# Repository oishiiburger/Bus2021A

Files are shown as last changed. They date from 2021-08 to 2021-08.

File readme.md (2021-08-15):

# Bus 2021A

This is a quick n' dirty bus design for a hobbyist computer system based around the [WD65C02](https://en.wikipedia.org/wiki/WDC_65C02). It is not meant to be fancy, but it should be functional. Features of the 65C02 which are unique to the WDC version are not exposed to the bus (i.e. VPB Vector-Pull Output, MLB Memory-Lock Output, and BE Bus Enable input). 4 pins (USER1 through USER4) are provided for peripheral expansion / experimentation / whatever.

The purpose of the bus is to allow for the use of a custom backplane so that several small boards to be easily connected. The backplane design is below, and protoboards intended for this bus are to come.

The bus mapping is [here](./Bus2021A.txt), but also printed on the backplane board.

## Bus 2021A backplane - 5 slot

The backplane features spots for 5 female pin headers, a DJ jack for 5v power and a power jumper (which can be broken out to a switch), a power LED, and a reset switch which is tied into the bus. 

A future revision might include blinkenlights on the backplane, but for now there will be space for those to be easily placed on one of the protoboards.

| PCB | Schematic |
| --- | --- |
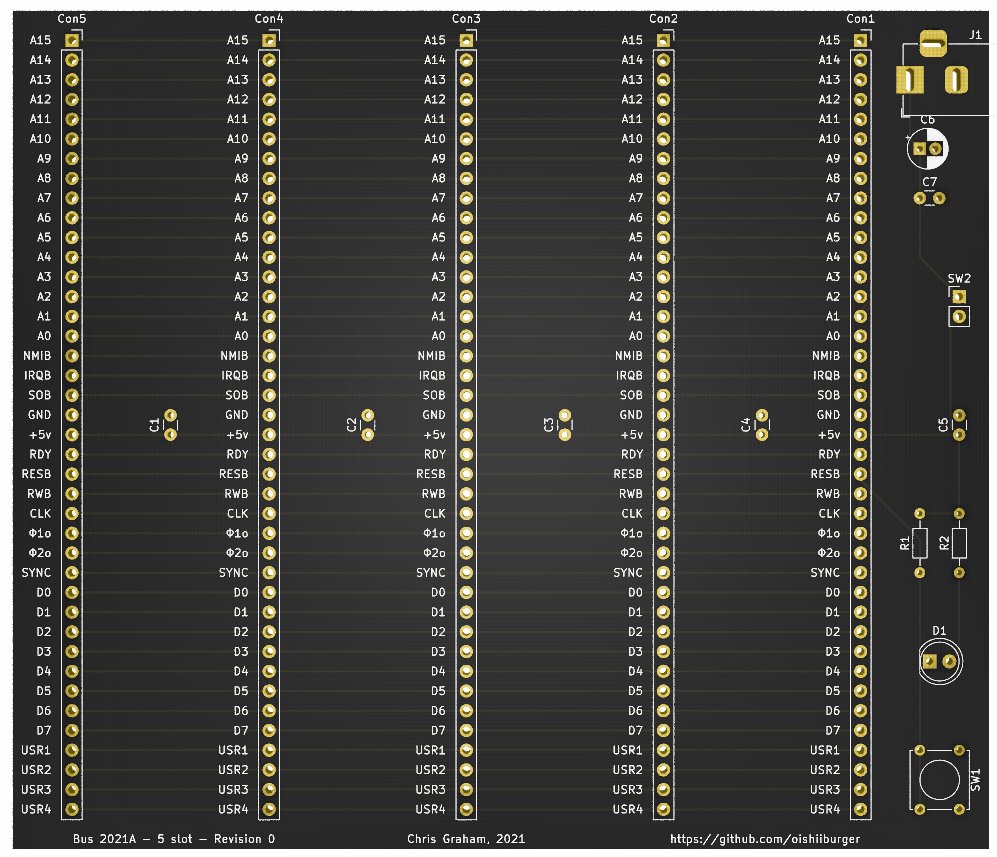
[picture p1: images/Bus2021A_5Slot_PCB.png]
Bus 2021A Rev0 PCB
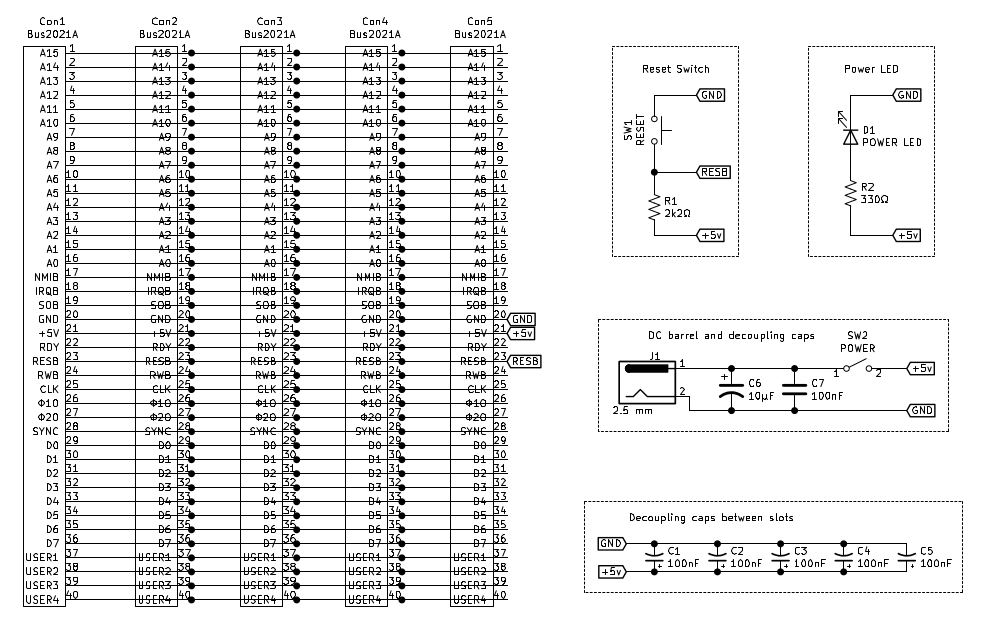
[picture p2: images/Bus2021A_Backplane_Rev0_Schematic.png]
Bus 2021A backplane - 5 slot schematic
|  |  |

Necessary kicad files are in [Bus2021A_5Slot](./Bus2021A_5Slot).

## Bus 2021A Protoboard

The protoboard is intended to connect with the backplane using a 90-degree pin header. It is designed as an easy and straightforward platform to interface with the bus and features a total project grid of 30x40 (1200 solder points). It has power rails vertically on either side with ground also horizontal on row 6, and the bus overall extends into the first three rows from the bottom (effectively a stripboard), all to keep distances shorter for wiring. The project grid not counting the rails or bus extension is 912 solder points. The board is labeled front and back on both axes.

The overall layout is:

```
Rows 1-3    :   Bus extension
Rows 4-5    :   Connected vertically
Rows 7-30   :   Project space (between power rails)
```

The purpose of the vertical connection between rows 4 and 5 is for easy installation of blinkenlights on the board using individual LEDs and resistors or LED bar graphs and resistor arrays. These rows can also be used for arbitrary circut connections without having to solder and resolder multiple wires.

Necessary files are [here](./Bus2021A_Protoboard).

| Protoboard front | Protoboard rear |
| --- | --- |
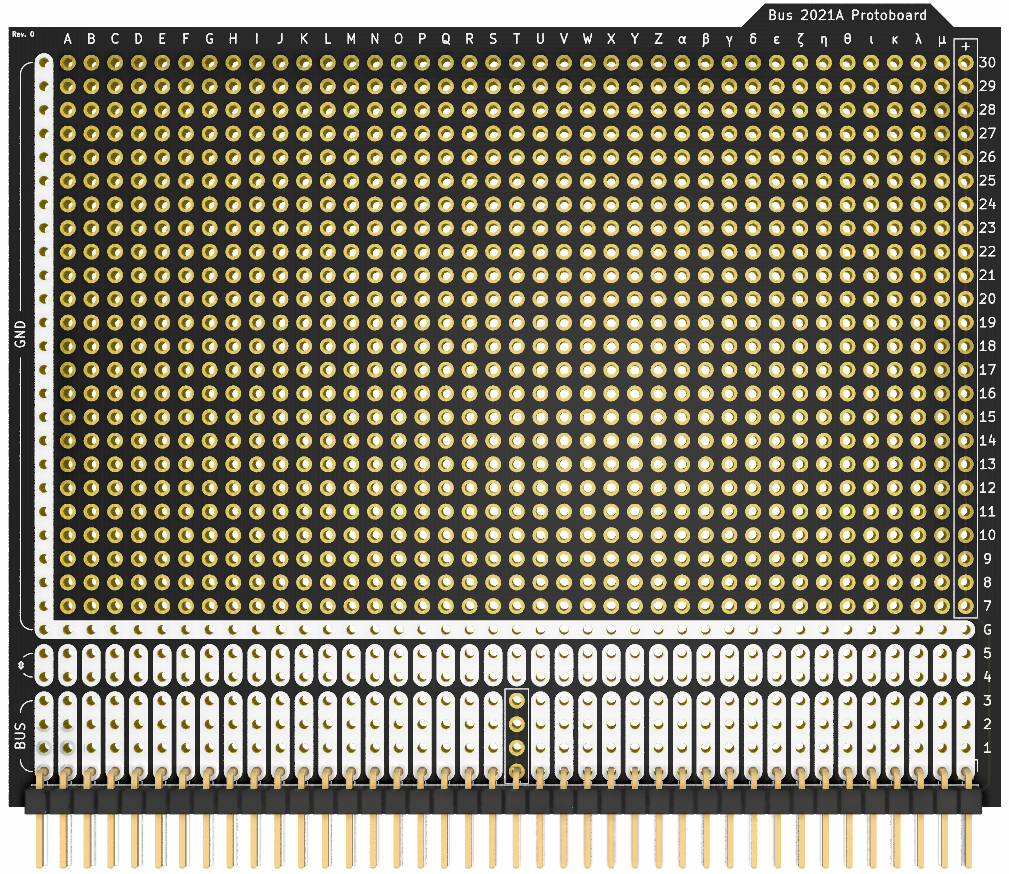
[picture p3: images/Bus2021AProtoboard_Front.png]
Protoboard front
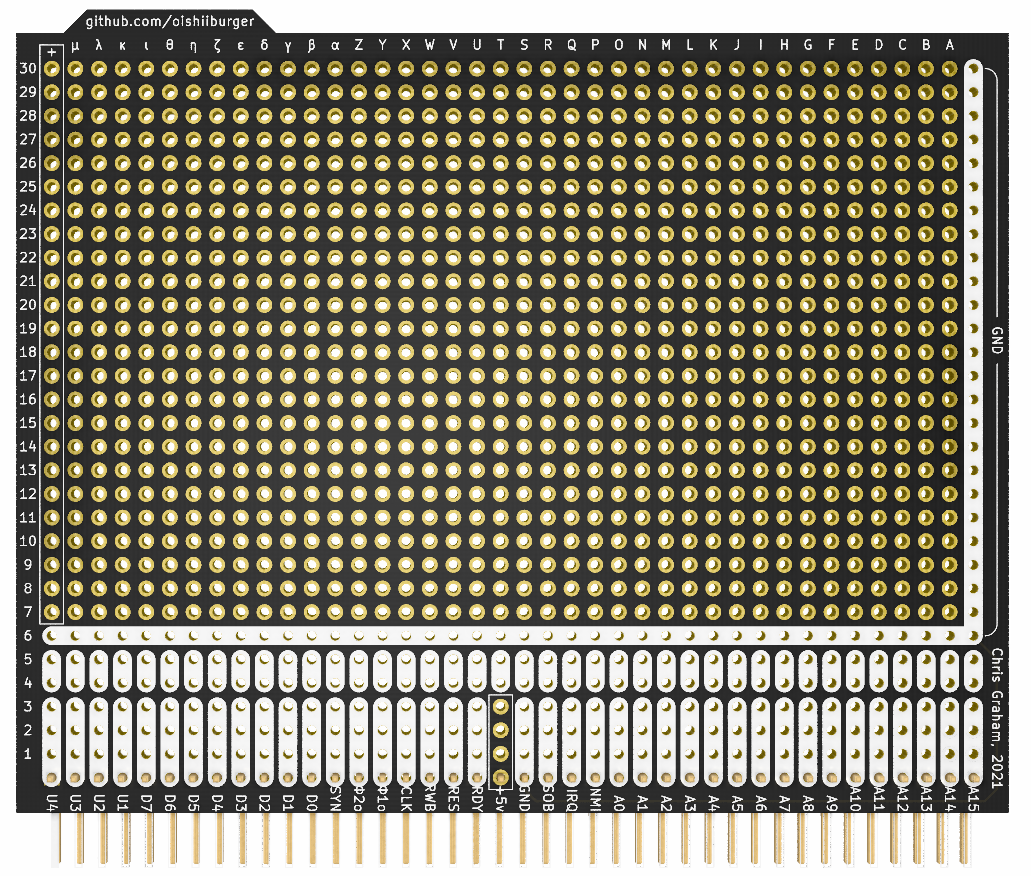
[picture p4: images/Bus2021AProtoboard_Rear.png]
Protoboard rear
|  |  |

## Symbols / footprints

A symbol for the bus and a footprint for the headers on the protoboard are in the [library folder](./Bus2021A_library).

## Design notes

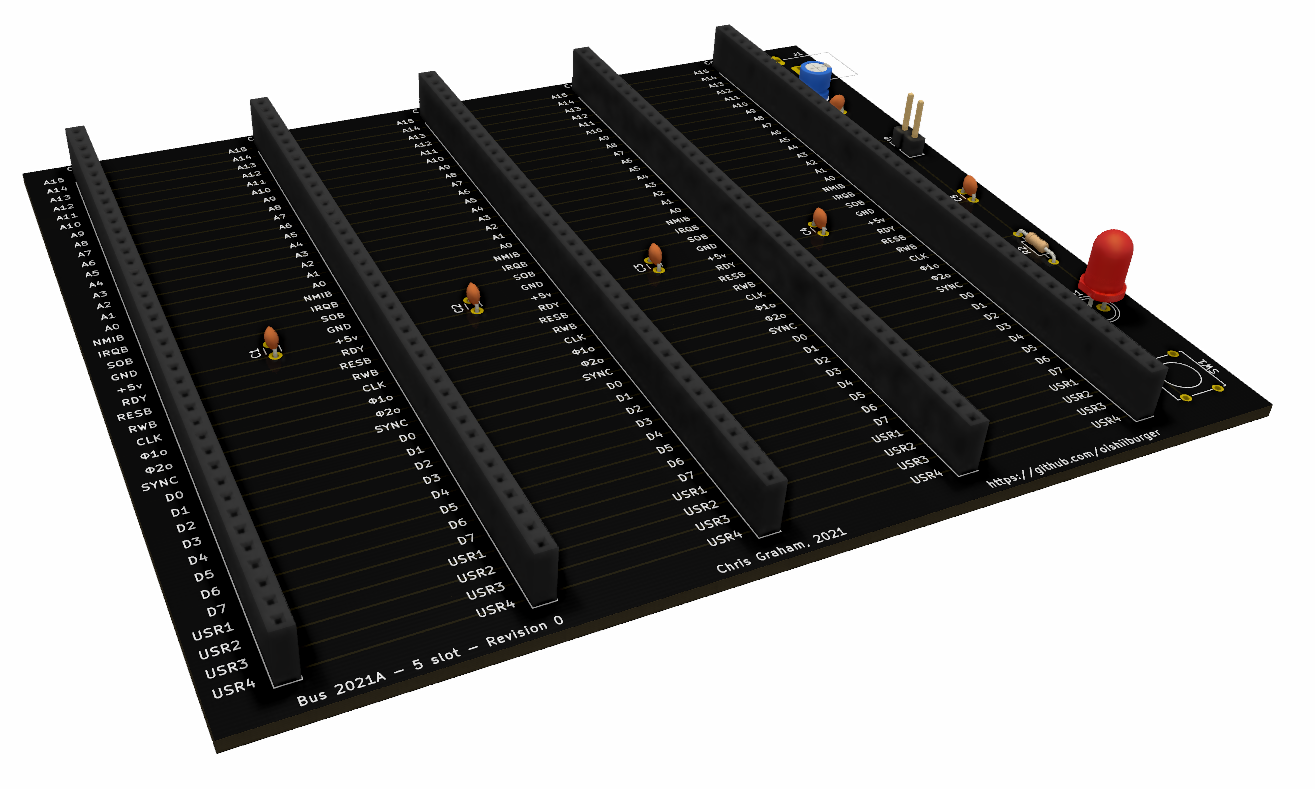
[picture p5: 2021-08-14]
images/Bus2021ABackplane_Side.png

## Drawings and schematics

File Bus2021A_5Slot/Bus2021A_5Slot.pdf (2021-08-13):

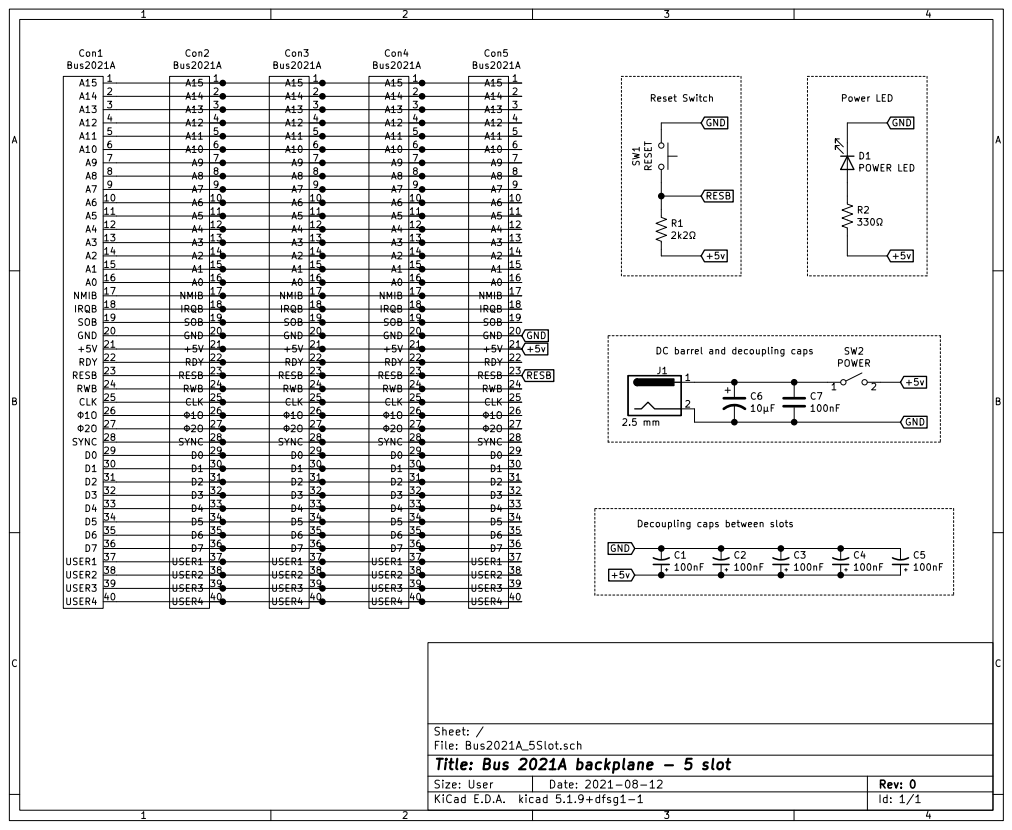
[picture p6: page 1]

A11 | 5 A10 6 A9 7 A8 8 A7 9 Con3 Bus2021A | A11 | 5 A10 6 A9 7 A8 8 A7 9 Con4 Bus2021A | A11 | 5 A10 6 A9 7 A8 8 A7 9 Con5 Bus2021A
A15 | 10 A5 11 A4 12 A3 13 A2 14 A1 15 A0 16 NMIB 17 1 A6 | A15 | 10 A5 11 A4 12 A3 13 A2 14 A1 15 A0 16 NMIB 17 1 A6 | A15 | 10 A5 11 A4 12 A3 13 A2 14 A1 15 A0 16 NMIB 17 1 A6
2O | 27 SYNC 28 D0 29 A13 30 D2 31 D3 32 D4 33 D5 34 D6 35 D7 36 USER1 37 USER2 38 USER3 39 3 D1 | 2O | 27 SYNC 28 D0 29 A13 30 D2 31 D3 32 D4 33 D5 34 D6 35 D7 36 USER1 37 USER2 38 USER3 39 3 D1 | 2O | 27 SYNC 28 D0 29 A13 30 D2 31 D3 32 D4 33 D5 34 D6 35 D7 36 USER1 37 USER2 38 USER3 39 3 D1

Decoupling caps between slots

File: Bus2021A_5Slot.sch Sheet: /
Id: 1/1 Title: Bus 2021A backplane - 5 slot

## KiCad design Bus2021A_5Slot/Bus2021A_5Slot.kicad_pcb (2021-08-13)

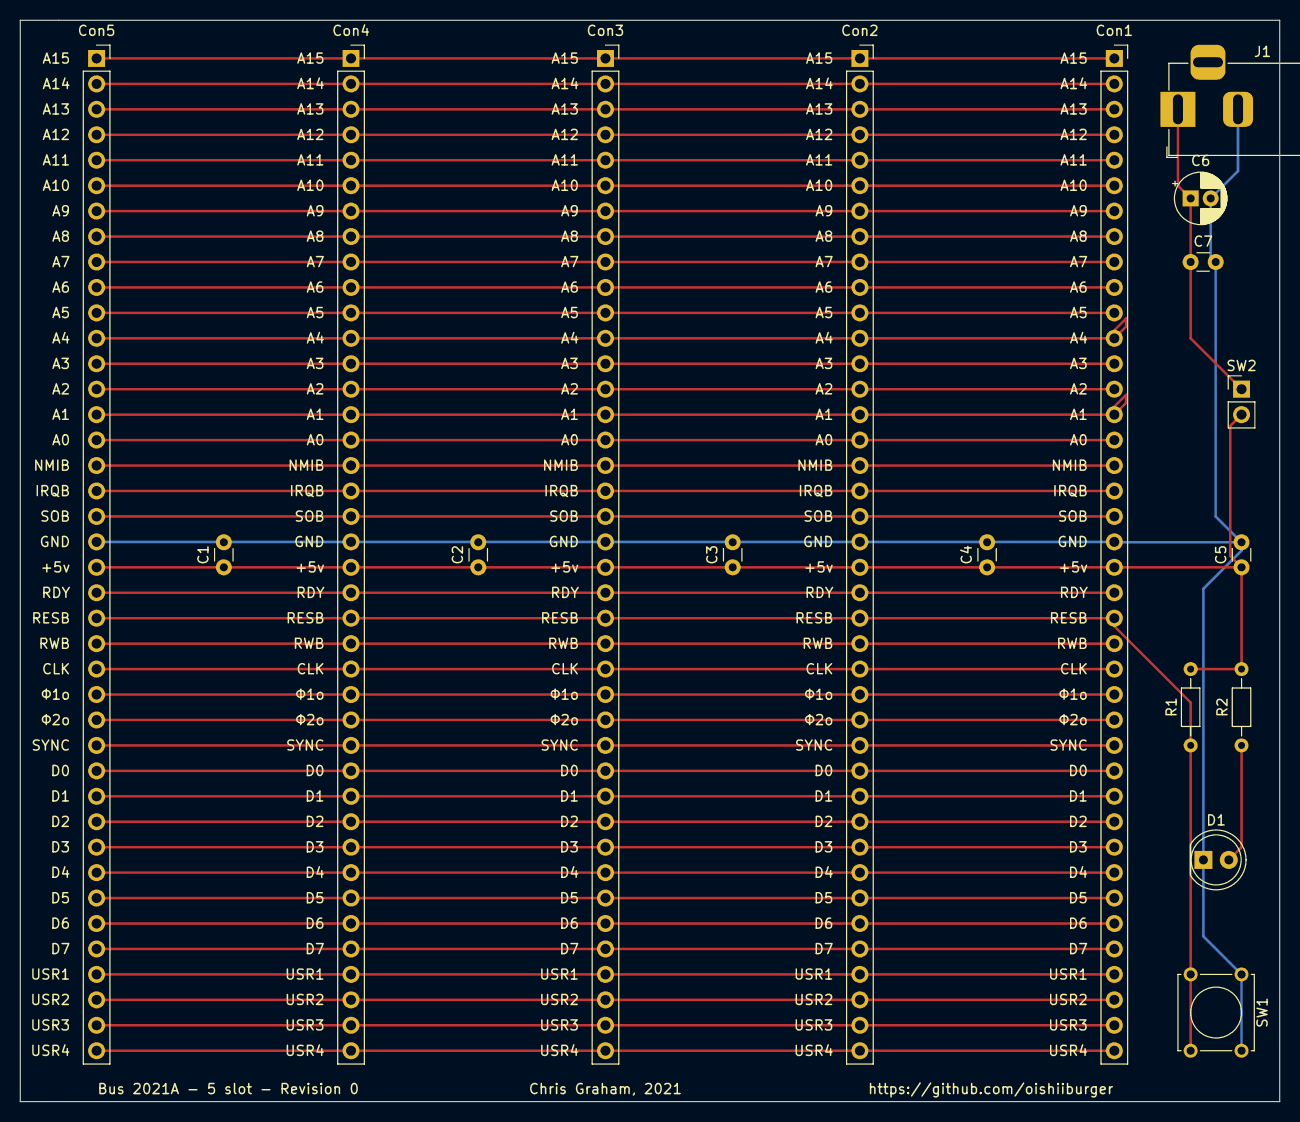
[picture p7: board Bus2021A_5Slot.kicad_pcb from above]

Board: 2 copper layers, 125.7 x 108.0 mm, 18 parts (0 on the bottom side), 42 nets.

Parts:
C1, C2, C3, C4, C5, C7: 100nF; C_Disc_D3.0mm_W1.6mm_P2.50mm
C6: 10μF; CP_Radial_D5.0mm_P2.00mm
Con1, Con2, Con3, Con4, Con5: Bus2021A; PinSocket_1x40_P2.54mm_Vertical
D1: POWER LED; LED_D5.0mm
J1: 2.5 mm; BarrelJack_Horizontal
R1: 2k2Ω; R_Axial_DIN0204_L3.6mm_D1.6mm_P7.62mm_Horizontal
R2: 330Ω; R_Axial_DIN0204_L3.6mm_D1.6mm_P7.62mm_Horizontal
SW1: RESET; SW_Tactile_Straight_KSL0Axx1LFTR
SW2: POWER; PinHeader_1x02_P2.54mm_Vertical

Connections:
+5v: C1.1, C2.1, C3.1, C4.1, C5.1, Con1.21, Con2.21, Con3.21, Con4.21, Con5.21, R1.2, R2.2, SW2.2
GND: C1.2, C2.2, C3.2, C4.2, C5.2, C6.2, C7.2, Con1.20, Con2.20, Con3.20, Con4.20, Con5.20, D1.1, J1.2, SW1.1
unnamed: C6.1, C7.1, J1.1, SW2.1
unnamed: Con1.1, Con2.1, Con3.1, Con4.1, Con5.1
unnamed: Con1.2, Con2.2, Con3.2, Con4.2, Con5.2
unnamed: Con1.3, Con2.3, Con3.3, Con4.3, Con5.3
unnamed: Con1.4, Con2.4, Con3.4, Con4.4, Con5.4
unnamed: Con1.5, Con2.5, Con3.5, Con4.5, Con5.5
unnamed: Con1.6, Con2.6, Con3.6, Con4.6, Con5.6
unnamed: Con1.7, Con2.7, Con3.7, Con4.7, Con5.7
unnamed: Con1.8, Con2.8, Con3.8, Con4.8, Con5.8
unnamed: Con1.9, Con2.9, Con3.9, Con4.9, Con5.9
unnamed: Con1.10, Con2.10, Con3.10, Con4.10, Con5.10
unnamed: Con1.11, Con2.11, Con3.11, Con4.11, Con5.11
unnamed: Con1.12, Con2.12, Con3.12, Con4.12, Con5.12
unnamed: Con1.13, Con2.13, Con3.13, Con4.13, Con5.13
unnamed: Con1.14, Con2.14, Con3.14, Con4.14, Con5.14
unnamed: Con1.15, Con2.15, Con3.15, Con4.15, Con5.15
unnamed: Con1.16, Con2.16, Con3.16, Con4.16, Con5.16
unnamed: Con1.17, Con2.17, Con3.17, Con4.17, Con5.17
unnamed: Con1.18, Con2.18, Con3.18, Con4.18, Con5.18
unnamed: Con1.19, Con2.19, Con3.19, Con4.19, Con5.19
unnamed: Con1.22, Con2.22, Con3.22, Con4.22, Con5.22
unnamed: Con1.24, Con2.24, Con3.24, Con4.24, Con5.24
unnamed: Con1.25, Con2.25, Con3.25, Con4.25, Con5.25
unnamed: Con1.26, Con2.26, Con3.26, Con4.26, Con5.26
unnamed: Con1.27, Con2.27, Con3.27, Con4.27, Con5.27
unnamed: Con1.28, Con2.28, Con3.28, Con4.28, Con5.28
unnamed: Con1.29, Con2.29, Con3.29, Con4.29, Con5.29
unnamed: Con1.30, Con2.30, Con3.30, Con4.30, Con5.30
unnamed: Con1.31, Con2.31, Con3.31, Con4.31, Con5.31
unnamed: Con1.32, Con2.32, Con3.32, Con4.32, Con5.32
unnamed: Con1.33, Con2.33, Con3.33, Con4.33, Con5.33
unnamed: Con1.34, Con2.34, Con3.34, Con4.34, Con5.34
unnamed: Con1.35, Con2.35, Con3.35, Con4.35, Con5.35
unnamed: Con1.36, Con2.36, Con3.36, Con4.36, Con5.36
unnamed: Con1.37, Con2.37, Con3.37, Con4.37, Con5.37
unnamed: Con1.38, Con2.38, Con3.38, Con4.38, Con5.38
unnamed: Con1.39, Con2.39, Con3.39, Con4.39, Con5.39
unnamed: Con1.40, Con2.40, Con3.40, Con4.40, Con5.40
unnamed: D1.2, R2.1
RESB: Con1.23, Con2.23, Con3.23, Con4.23, Con5.23, R1.1, SW1.2

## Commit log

2021-08-13 Added Rev0 5 slot schematic and gerbers
    [Bus2021A_5Slot-B_Cu.gbr, Bus2021A_5Slot-B_Mask.gbr, Bus2021A_5Slot-B_Paste.gbr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]
2021-08-13 Added PCB image
2021-08-14 Added protoboard gerbers; updated readme
    [Bus2021A_Protoboard-B_Cu.gbr, Bus2021A_Protoboard-B_Mask.gbr, Bus2021A_Protoboard-B_Paste.gbr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]
2021-08-15 Cleaned up files
    [Bus2021A_5Slot-B_Cu.gbr, Bus2021A_5Slot-B_Mask.gbr, Bus2021A_5Slot-B_Paste.gbr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]
